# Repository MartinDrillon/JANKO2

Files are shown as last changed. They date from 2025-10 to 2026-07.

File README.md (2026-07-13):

# Clavicore 0.1

Le Clavicore est un contrôleur midi sensible à la vélocité. Il est basé sur la disposition Janko. 
Il fonctionne grâce à des interrupteurs MX magnétiques et un Teensy 4.1.  

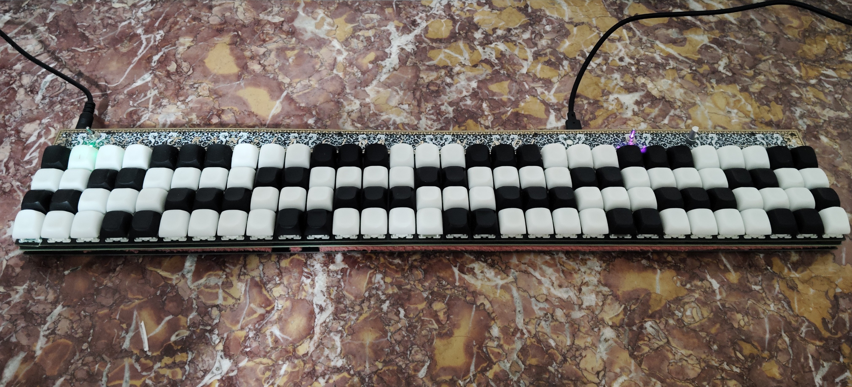
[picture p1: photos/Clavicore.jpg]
Clavicore


---

## JANKO LAYOUT

Contrairement à un piano standard, l’écart physique entre les touches correspond à l’écart musical entre les notes. Il y a un ton de différence sur les lignes et un demi-ton sur les colonnes. Toutes les gammes partagent le même doigté pour des accords identiques et sont jouées de la même manière.  

https://en.wikipedia.org/wiki/Jank%C3%B3_keyboard

## FONCTIONNEMENT

La position des touches est suivie grâce à des capteurs halls. Huit multiplexeurs permettent de transmettre le voltage émis par les 120 capteurs au Teensy. Ses deux ADC échantillonnent chaque touche en 10 bit à 11,4 kHz environ. Plus un touche est enfoncé vite, plus le niveau sonore associé au signal midi est élevé.

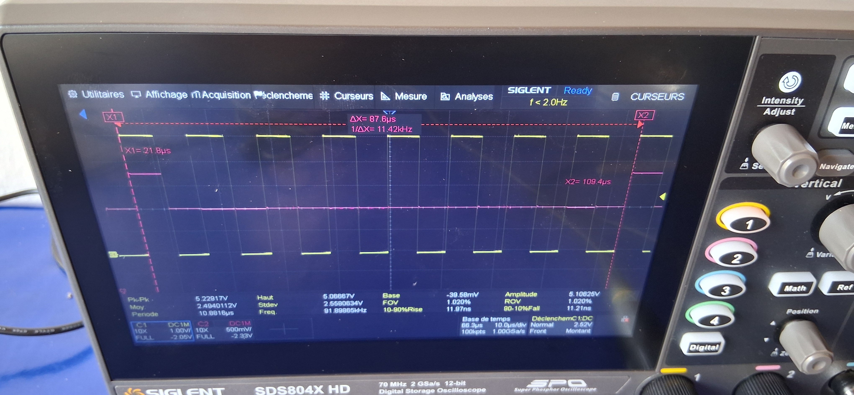
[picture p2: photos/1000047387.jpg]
Une des quatre lignes de sélection du multipleur en jaune, sa sortie en rose, avec une touche pressée : 
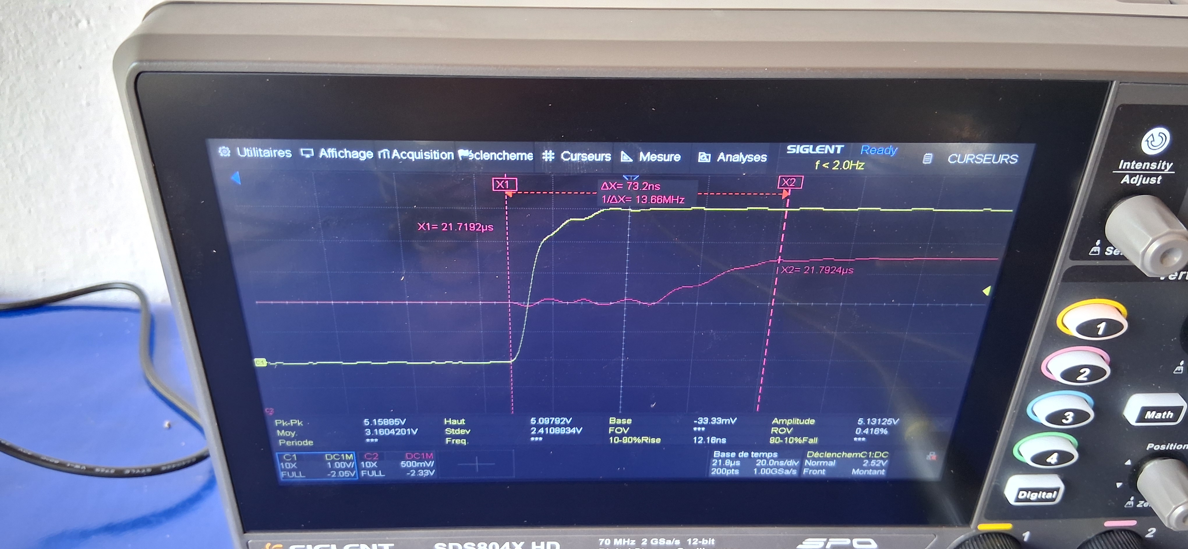
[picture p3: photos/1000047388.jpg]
Stabilisation du signal en sortie du multiplexeur après un changement de channel vers une touche pressée : 

Le schéma du clavicore est disponible ici : 
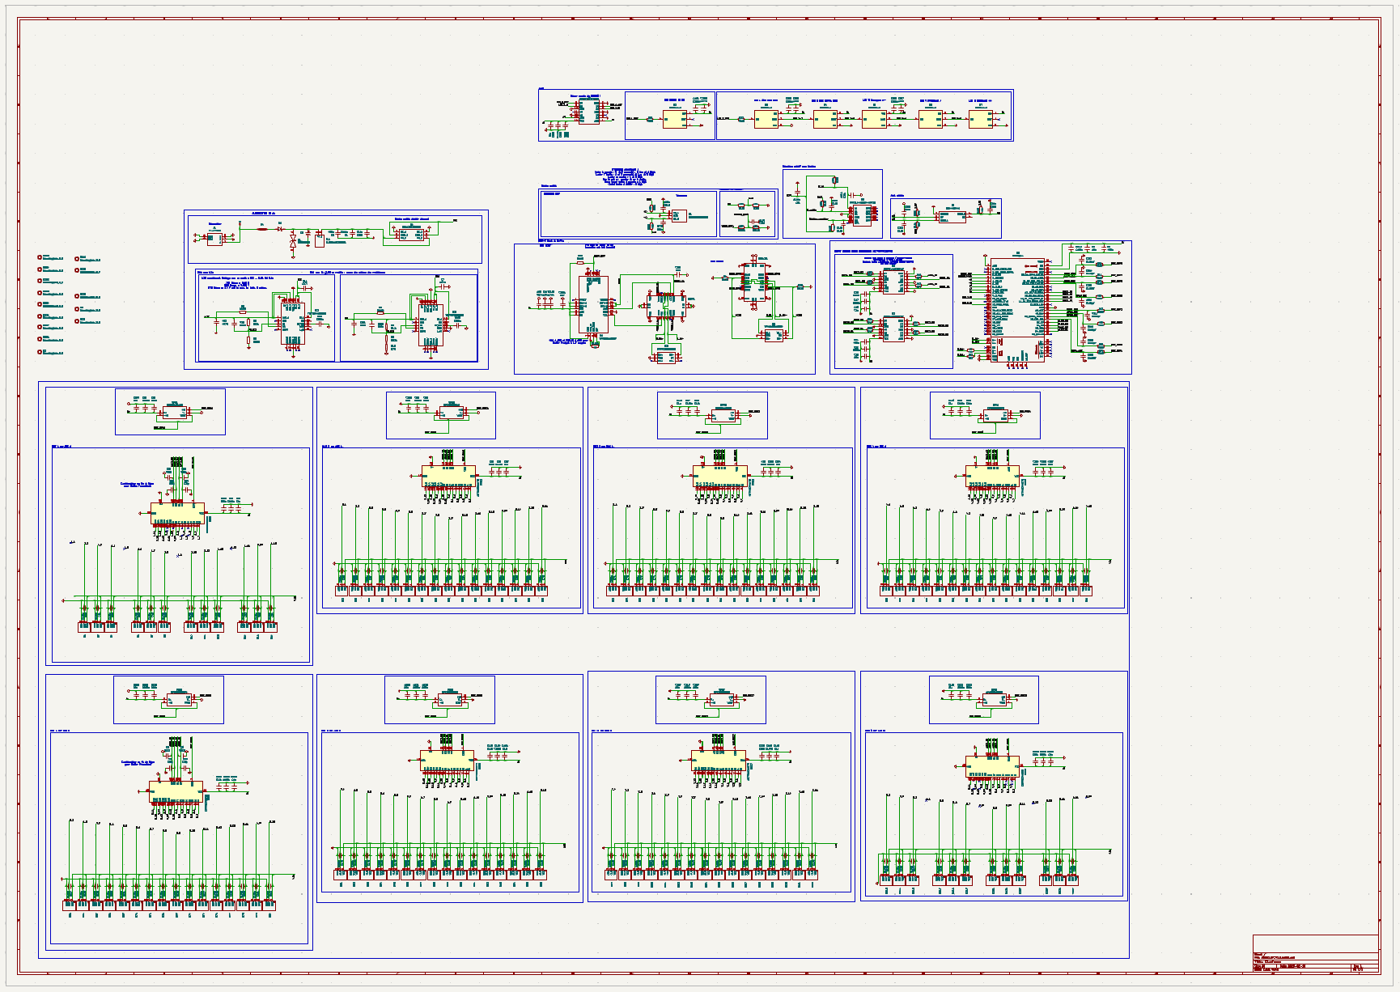
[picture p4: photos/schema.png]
Schéma du clavicore
 

## DÉMONSTRATION

Pour la démonstration de la dynamique de jeu.
https://youtube.com/shorts/Zl-sIEAEMYA?feature=share

Après deux semaines de pratique. Je ne suis pas musicien. Je sais qu’il n’y avait pas besoin de faire un clavier dynamique si c’est pour jouer du clavecin.
https://www.youtube.com/shorts/t3_tYI92ahw

Pour l’esthétique. C’est du plaqué or. J’ai vectorisé le texte du couvercle d’un clavecin ancien et diverses autres images.  
https://youtube.com/shorts/kKriU0rGM7M?feature=share

## LA SUITE

* Faire un vrais boitier
* Recommencer avec une disposition Wiki-Haydn et un STM32 ! 
* Intégrer quelques modules de synthé directement dans le Teensy, si possible ? Voir un séquenceur, etc. 

---

### CREDIT

Pour la preuve qu’il est possible de calculer efficacement une dynamique de jeu avec des capteurs halls :  
https://github.com/aleathwick/midi_hammer

Pour la preuve qu’on peut jouer avec des touches MX classiques :  
https://github.com/KOOPInstruments/melodicade_mx

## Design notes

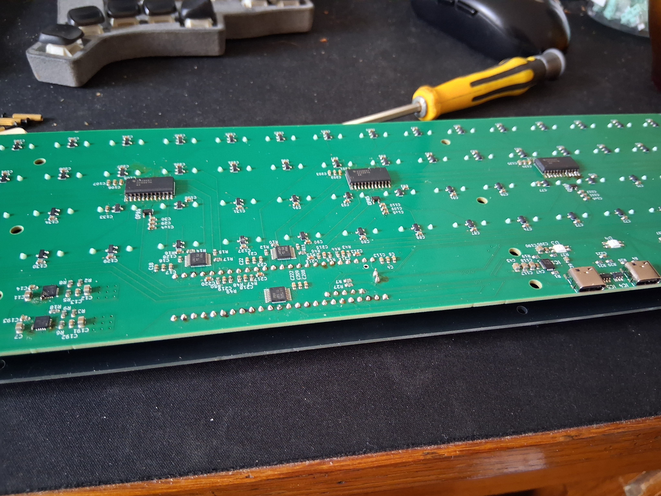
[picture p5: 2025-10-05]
photos/Clavicore_0_1_PCB.jpg

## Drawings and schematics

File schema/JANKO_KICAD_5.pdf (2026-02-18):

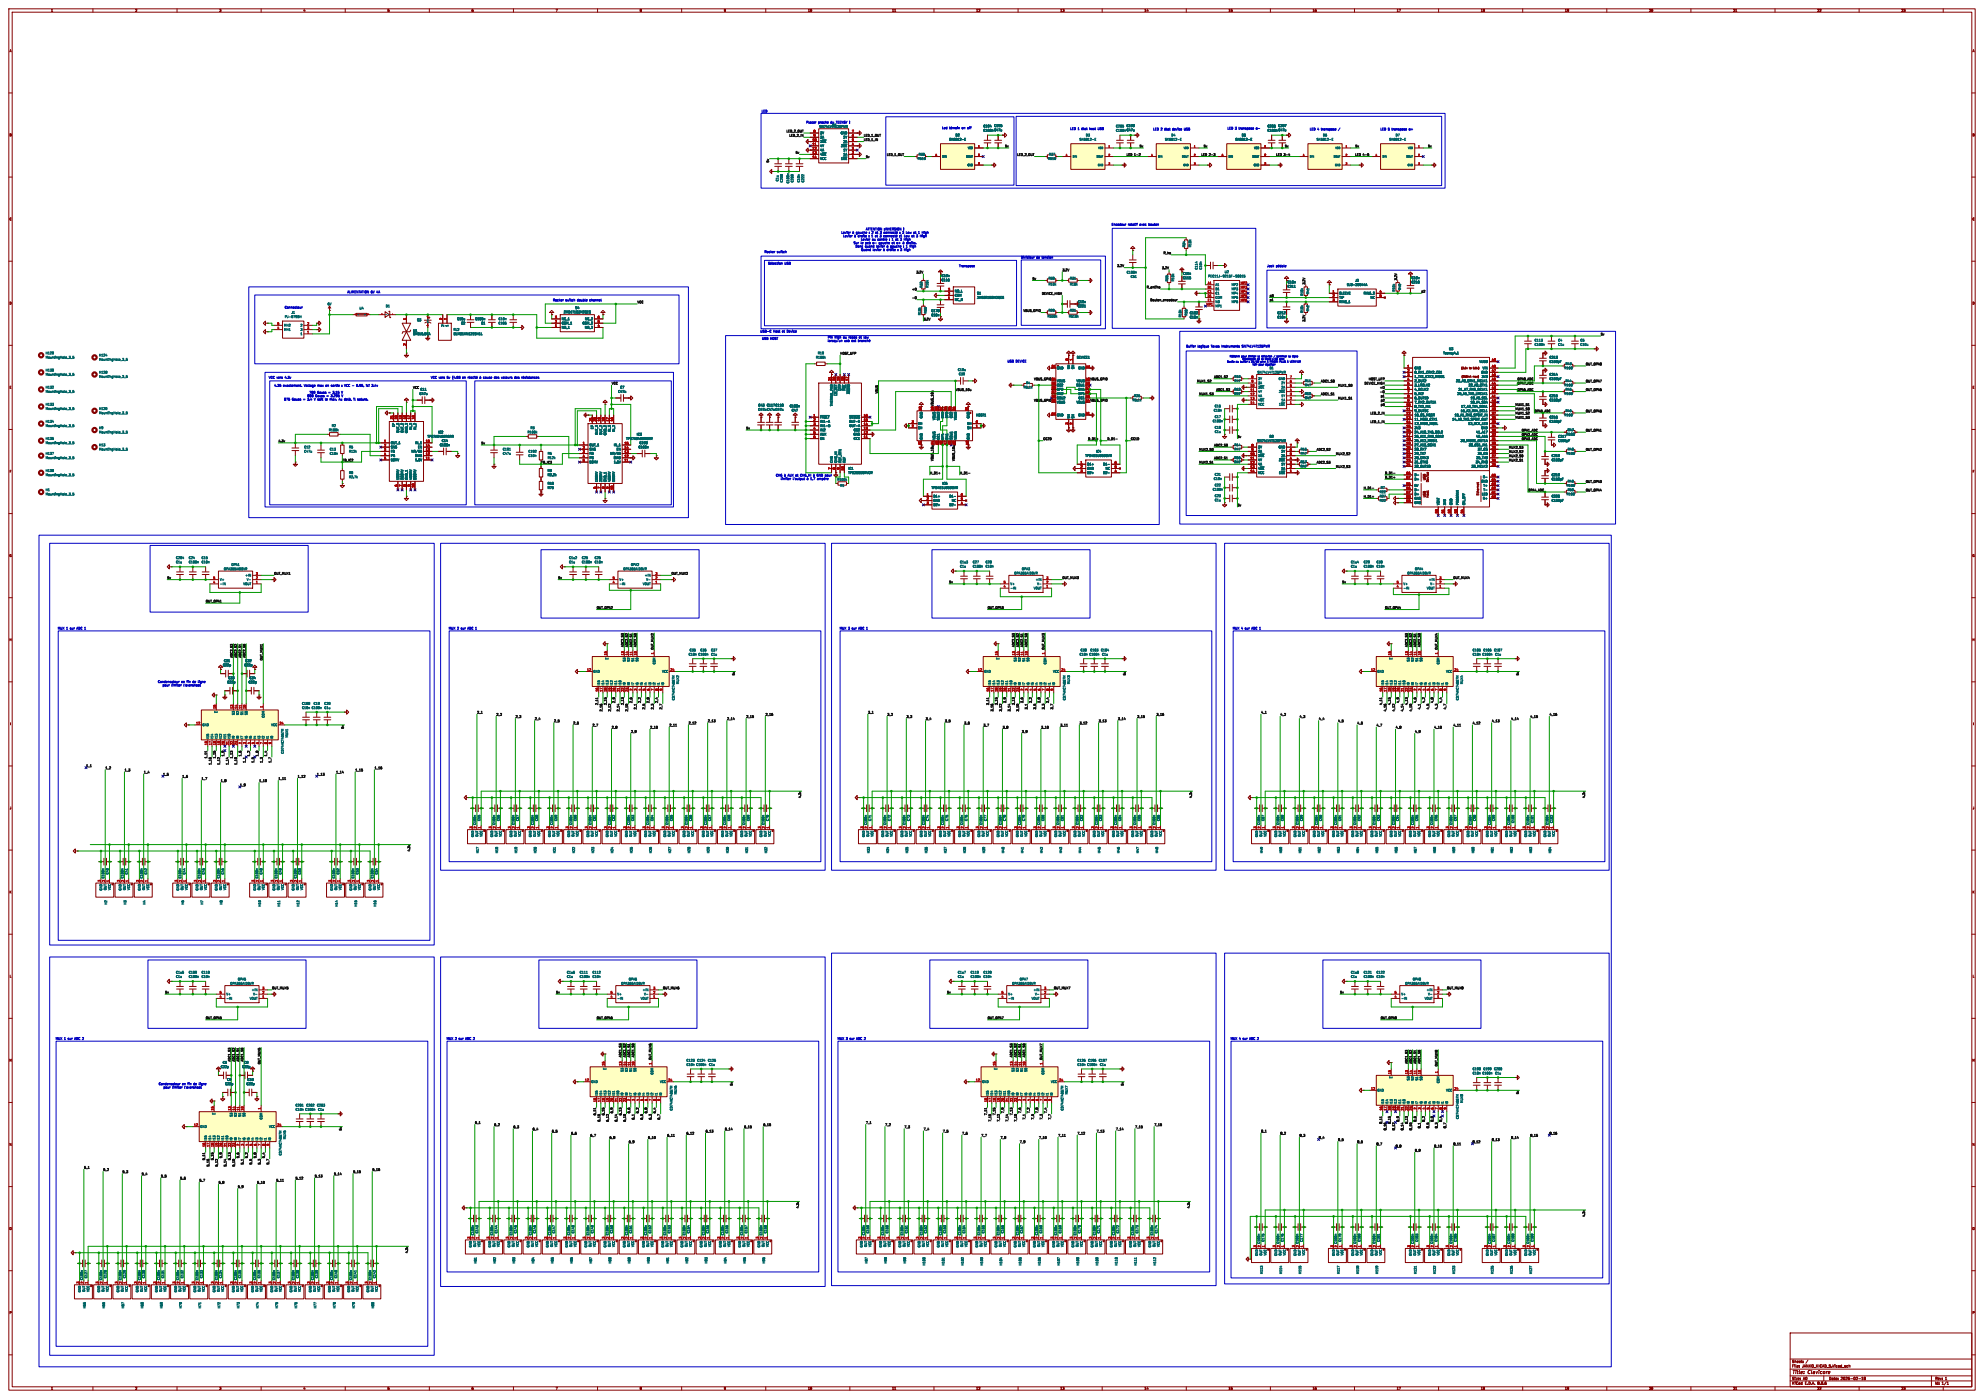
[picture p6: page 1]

Led þÿtémoin on off ALIMENTATION 6V 4A

LED 1 þÿétat host USB

ATTENTION þÿ: /INVERSION ! Levier þÿàgauche : 2 et 3 þÿconnecté : 3 Low et 1 High
3.2V VBUS

Levier þÿàdroite : 1 et 3 þÿconnecté þÿ: /1 Low et 3 High
Levier au centre : 1 et 3 High Sur le pcb o- gauche et o+ þÿàdroite. Donc quand levier þÿàgauche : 1 high Quand levier þÿàdroite : þÿ /3high

þÿSélection USB USB-C Host et Device

Transpose CHG þÿàAUX et CHG_HI þÿàGND pour

Pin high au repos et low

þÿImpédance de la trace : 50 ohm

15 ~{DEBUG}16 ~{AUDIO}17 ~{POL}18 ~{UFP}19

3 H69 OUT_1 1 800MV 10 1.6V 11 BIAS 12 NR/SS 13 EN 14

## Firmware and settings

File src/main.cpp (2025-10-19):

// JANKO2 - 8x16 MUX Controller with dual-ADC parallel scanning
// True parallel scanning: ADC0 + ADC1 simultaneous reads

#include <Arduino.h>
#include <ADC.h>
#include "config.h"
#include "simple_leds.h"
#include "velocity_engine.h"
#include "velocity_calc.h"
#include "calibration.h"
#include "note_map.h"
#include "io_state.h"
#include "key_state.h"
#include "calibration.h"
#include "midi_out.h"
#include <imxrt.h>  // pour DWT cycle counter (Teensy 4.x)
#if DEBUG_ADC_MONITOR
#include "adc_monitor.h"
#endif

// === Runtime velocity gamma (adjustable via encoder) ===
float gVelocityGamma = kVelocityGammaDefault;

// === ADC Instance ===
static ADC gAdc;

// === Fast MUX Channel Switching LUT ===
// Pre-calculated GPIO states for each channel (0-15)
struct ChannelGPIO {
    uint8_t groupA_S0, groupA_S1, groupA_S2, groupA_S3;
    uint8_t groupB_S0, groupB_S1, groupB_S2, groupB_S3;
};

// LUT for fast channel switching (avoids bit operations in loop)
static constexpr ChannelGPIO CHANNEL_LUT[16] = {
    // Ch0: 0000
    {LOW, LOW, LOW, LOW, LOW, LOW, LOW, LOW},
    // Ch1: 0001  
    {HIGH, LOW, LOW, LOW, HIGH, LOW, LOW, LOW},
    // Ch2: 0010
    {LOW, HIGH, LOW, LOW, LOW, HIGH, LOW, LOW},
    // Ch3: 0011
    {HIGH, HIGH, LOW, LOW, HIGH, HIGH, LOW, LOW},
    // Ch4: 0100
    {LOW, LOW, HIGH, LOW, LOW, LOW, HIGH, LOW},
    // Ch5: 0101
    {HIGH, LOW, HIGH, LOW, HIGH, LOW, HIGH, LOW},
    // Ch6: 0110
    {LOW, HIGH, HIGH, LOW, LOW, HIGH, HIGH, LOW},
    // Ch7: 0111
    {HIGH, HIGH, HIGH, LOW, HIGH, HIGH, HIGH, LOW},
    // Ch8: 1000
    {LOW, LOW, LOW, HIGH, LOW, LOW, LOW, HIGH},
    // Ch9: 1001
    {HIGH, LOW, LOW, HIGH, HIGH, LOW, LOW, HIGH},
    // Ch10: 1010
    {LOW, HIGH, LOW, HIGH, LOW, HIGH, LOW, HIGH},
    // Ch11: 1011
    {HIGH, HIGH, LOW, HIGH, HIGH, HIGH, LOW, HIGH},
    // Ch12: 1100
    {LOW, LOW, HIGH, HIGH, LOW, LOW, HIGH, HIGH},
    // Ch13: 1101
    {HIGH, LOW, HIGH, HIGH, HIGH, LOW, HIGH, HIGH},
    // Ch14: 1110
    {LOW, HIGH, HIGH, HIGH, LOW, HIGH, HIGH, HIGH},
    // Ch15: 1111
    {HIGH, HIGH, HIGH, HIGH, HIGH, HIGH, HIGH, HIGH}
};

// === USB MIDI is built-in on Teensy ===
// No additional setup required

// === Calibration Removed ===
// Dynamic calibration logic has been fully removed in the simplified velocity design.
// Thresholds are now fixed constants defined in calibration.h. All related state,
// histograms, and timing have been stripped to reduce latency.

// --- Scanning State ---
uint8_t currentChannel = 0;
uint32_t lastScanUs = 0;
// Frame rate instrumentation
#if DEBUG_FRAME_RATE
static uint32_t gFrameCount = 0;
static uint32_t gLastFrameReportMs = 0;
#endif
// Profiling instrumentation
#if DEBUG_PROFILE_SCAN
static uint64_t gAccumChannelTimeUs = 0;   // somme durées individuelles channels
static uint32_t gChannelSamples = 0;       // nombre de channels mesurés
static uint32_t gFrameAccumTimeUs = 0;     // somme durées frames
static uint32_t gFrameSamples = 0;         // nombre de frames mesurées
static uint32_t gFrameStartUs = 0;         // début frame courante
static uint32_t gChannelMaxUs = 0;         // max channel observé sur intervalle
#endif
// Duplicate detection instrumentation
#if DEBUG_DUPLICATE_DETECT
static uint32_t gDuplicatePairs = 0;          // total paires détectées identiques
static uint32_t gDuplicateFrames = 0;         // frames contenant au moins 1 duplication
static uint32_t gFramesSinceDupPrint = 0;     // compteur de frames pour périodicité
#endif



// --- Function Declarations ---
// (Calibration functions removed)

// --- Dual MUX Control Functions ---
// --- Ultra-Fast MUX Channel Setting with LUT ---
void setMuxChannel(uint8_t channel) {
    const ChannelGPIO& gpio = CHANNEL_LUT[channel];
    
    // Set Group A (S0-S3) with pre-calculated values
    digitalWriteFast(kMuxGroupA_S0, gpio.groupA_S0);
    digitalWriteFast(kMuxGroupA_S1, gpio.groupA_S1);
    digitalWriteFast(kMuxGroupA_S2, gpio.groupA_S2);
    digitalWriteFast(kMuxGroupA_S3, gpio.groupA_S3);
    
    // Set Group B (S0-S3) with pre-calculated values
    digitalWriteFast(kMuxGroupB_S0, gpio.groupB_S0);
    digitalWriteFast(kMuxGroupB_S1, gpio.groupB_S1);
    digitalWriteFast(kMuxGroupB_S2, gpio.groupB_S2);
    digitalWriteFast(kMuxGroupB_S3, gpio.groupB_S3);
}

void initializeDualMux() {
    // Initialize Group A control pins
    pinMode(kMuxGroupA_S0, OUTPUT);
    pinMode(kMuxGroupA_S1, OUTPUT);
    pinMode(kMuxGroupA_S2, OUTPUT);
    pinMode(kMuxGroupA_S3, OUTPUT);
    
    // Initialize Group B control pins
    pinMode(kMuxGroupB_S0, OUTPUT);
    pinMode(kMuxGroupB_S1, OUTPUT);
    pinMode(kMuxGroupB_S2, OUTPUT);
    pinMode(kMuxGroupB_S3, OUTPUT);
    
    // Standard ADC configuration for now (we'll optimize with ADC lib later)
    analogReadResolution(kAdcResolution);
    
    // === ADC Library Configuration ===
    // Calibrate both ADCs
    gAdc.adc0->calibrate();
    gAdc.adc1->calibrate();
    
    // Set to no averaging for maximum speed
    gAdc.adc0->setAveraging(1);
    gAdc.adc1->setAveraging(1);
    
    // Set maximum conversion speed
    gAdc.adc0->setConversionSpeed(ADC_CONVERSION_SPEED::VERY_HIGH_SPEED);
    gAdc.adc1->setConversionSpeed(ADC_CONVERSION_SPEED::VERY_HIGH_SPEED);
    
    // Set maximum sampling speed
    gAdc.adc0->setSamplingSpeed(ADC_SAMPLING_SPEED::VERY_HIGH_SPEED);
    gAdc.adc1->setSamplingSpeed(ADC_SAMPLING_SPEED::VERY_HIGH_SPEED);
    
    // Serial prints removed for performance
}

// --- Cycle counter init (DWT) ---
static inline void enableCycleCounter() {
    // Teensy 4.x (IMXRT) expose ARM DWT registers via imxrt.h macros
    // ARM_DEMCR_TRCENA enables trace (needed for DWT cycle counter)
    ARM_DEMCR |= ARM_DEMCR_TRCENA;    // enable trace
    ARM_DWT_CYCCNT = 0;               // reset cycle counter
    ARM_DWT_CTRL |= 1;                // enable CYCCNT (bit 0)
}
static inline uint32_t readCycleCounter() { return ARM_DWT_CYCCNT; }

// --- Optimized Scanning with LUT and Synchronized ADC ---
void scanChannelDualADC(uint8_t channel) {
    // Optional debug channel freeze
    #if (DEBUG_FREEZE_CHANNEL >= 0)
    channel = DEBUG_FREEZE_CHANNEL % N_CH;
    #endif

    // Set MUX channel with ultra-fast LUT (both groups simultaneously)
    setMuxChannel(channel);

    // Allow MUX outputs + sample/hold buffers to settle
    delayMicroseconds(kSettleMicros);

    // Timestamp as close as possible to first acquisition (pre-loop)
    uint32_t timestamp_us = micros();

        // Perform four synchronized dual-ADC reads (must do all 4 to avoid cloned values)
        // EXACT SPECIFIED IMPLEMENTATION with selectable order and per-pair debug
        uint16_t values[8];
    for (int i = 0; i < 4; ++i) {
            #if ADC_SYNC_ORDER == 0
                // Ordre (ADC0, ADC1) — souvent attendu par pedvide sur T4.1
                const int pin_adc0 = MUX_ADC_PINS[4 + i];  // 20,21,22,23
                const int pin_adc1 = MUX_ADC_PINS[i];      // 41,40,39,38
                gAdc.startSynchronizedSingleRead(pin_adc0, pin_adc1);
                ADC::Sync_result r = gAdc.readSynchronizedSingle();
                values[i]     = r.result_adc1;  // MUX i     → ADC1 → pins 41,40,39,38
                values[4 + i] = r.result_adc0;  // MUX 4+i   → ADC0 → pins 20,21,22,23
            #else
                // Ordre (ADC1, ADC0)
                const int pin_adc1 = MUX_ADC_PINS[i];      // 41,40,39,38
                const int pin_adc0 = MUX_ADC_PINS[4 + i];  // 20,21,22,23
                gAdc.startSynchronizedSingleRead(pin_adc1, pin_adc0);
                ADC::Sync_result r = gAdc.readSynchronizedSingle();
                values[i]     = r.result_adc1;  // MUX i     → ADC1
                values[4 + i] = r.result_adc0;  // MUX 4+i   → ADC0
            #endif

            #if DEBUG_PRINT_PAIRS
                // Pair debug removed
            #endif
            // Pause optionnelle entre paires pour éviter des lectures clonées.
            if (kPerPairDelayMicros > 0) {
                delayMicroseconds(kPerPairDelayMicros);
            } else if (kPerPairDelayCycles > 0) {
                // Attente fine en cycles CPU
                uint32_t start = readCycleCounter();
                while ((readCycleCounter() - start) < kPerPairDelayCycles) { __asm__ volatile("nop"); }
            }
        }

    // Process all 8 keys (always active; no calibration phase)
    for (uint8_t mux = 0; mux < 8; mux++) {
        VelocityEngine::processKey(mux, channel, values[mux], timestamp_us);
#if DEBUG_ADC_MONITOR
        // Met à jour le moniteur si c'est la combinaison surveillée
        AdcMonitor::updateIfMatch(mux, channel, values[mux], timestamp_us);
#endif
    }

#if DEBUG_DUPLICATE_DETECT
    // Détection duplication: compare valeurs[0..3] vs valeurs[4..7]
    bool frameDup = false; // dans ce channel
    for (int i=0;i<4;i++) {
        int16_t d = (int16_t)values[i] - (int16_t)values[4+i];
        if (d < 0) d = -d;
        if (d <= (int16_t)kDuplicateTolerance) {
            gDuplicatePairs++;
            frameDup = true;
        }
    }
    if (frameDup) gDuplicateFrames++;
#endif

    // Optional debug print
    // Value debug removed
}


void setup() {
    // Serial interface removed
    
    // Initialize dual MUX hardware
    initializeDualMux();
    setMuxChannel(currentChannel);
    lastScanUs = micros();
#if DEBUG_PROFILE_SCAN
    gFrameStartUs = lastScanUs;
#endif
    
    // Initialize LEDs
    simpleLedsInit();
    // Initialize I/O state (rocker pins)
    IoState::init();
    
    // Calibration LEDs no longer used (ensure off)
    setCalibrationLeds(false);

#if DEBUG_ADC_MONITOR
    AdcMonitor::begin();
#endif

#if DEBUG_FRAME_RATE && DEBUG_FRAME_RATE_TOGGLE_LED
    pinMode(13, OUTPUT); // LED intégrée Teensy
    digitalWriteFast(13, LOW);
#endif
    
    // Initialize velocity engine
    VelocityEngine::initialize();
    // Initialize MIDI output queue
    MidiOut::init();
    // Init static thresholds (Phase1 dynamique) and load velocity gamma from EEPROM
    calibrationInitStatic();
    // Load velocity gamma from EEPROM if available
    {
        uint16_t tmpLow[N_MUX][N_CH], tmpHigh[N_MUX][N_CH];
        float tmpGamma = kVelocityGammaDefault;
        if (EepromStore::load(tmpLow, tmpHigh, &tmpGamma)) {
            gVelocityGamma = tmpGamma;
        }
    }
    // Set LED brightness to constant value (no longer adjustable via encoder)
    simpleLedsSetBrightness(kLedBrightness);
    // Ne pas démarrer de calibration au boot: conserver les seuils EEPROM
    enableCycleCounter();
    
    // Ready banner removed
    
        // === ADC Pin Mapping Sanity Check (dynamic) ===
        // Pin mapping sanity print removed
    
    // Show current note mapping
    // printNoteMap removed (Serial use)
}

void loop() {
    const uint32_t nowUs = micros();
    // (Calibration state management removed)

    // === Main scanning loop ===
    // Prépare éventuel changement LED (sans show())
    simpleLedsUpdateInputState();
    if (kContinuousScan) {
        // Pas d'attente: enchaîne directement
        uint32_t t0 = micros();
        scanChannelDualADC(currentChannel);
        uint32_t t1 = micros();
#if DEBUG_PROFILE_SCAN
        uint32_t chDur = t1 - t0;
        gAccumChannelTimeUs += chDur;
        gChannelSamples++;
        if (chDur > gChannelMaxUs) gChannelMaxUs = chDur;
#endif
        currentChannel = (currentChannel + 1) % N_CH;
        if (currentChannel == 0) {
            g_acquisition.swapBuffers();
            // Phase2 ingestion frame pour médiane Low
            if (calibrationIsCollecting()) {
                calibrationFrameIngest(g_acquisition.workingValues); // workingValues encore valides juste après swap
            }
#if DEBUG_PROFILE_SCAN
            uint32_t nowUsFrame = micros();
            uint32_t frameDur = nowUsFrame - gFrameStartUs;
            gFrameStartUs = nowUsFrame;
            gFrameAccumTimeUs += frameDur;
            gFrameSamples++;
            if (gFrameSamples >= DEBUG_PROFILE_INTERVAL_FRAMES) {
                // Calculs moyens
                uint32_t avgFrameUs = gFrameAccumTimeUs / gFrameSamples;
                uint32_t avgChannelUs = gChannelSamples ? (uint32_t)(gAccumChannelTimeUs / gChannelSamples) : 0;
                Serial.printf("[PROFILE] frames=%lu avgFrame=%luus avgCh=%luus maxCh=%luus fps_est=%lu\n",
                              (unsigned long)gFrameSamples,
                              (unsigned long)avgFrameUs,
                              (unsigned long)avgChannelUs,
                              (unsigned long)gChannelMaxUs,
                              (unsigned long)(avgFrameUs ? (1000000UL / avgFrameUs) : 0));
                // reset interval
                gFrameAccumTimeUs = 0;
                gFrameSamples = 0;
                gAccumChannelTimeUs = 0;
                gChannelSamples = 0;
                gChannelMaxUs = 0;
            }
#endif
#if DEBUG_FRAME_RATE
            gFrameCount++;
#if DEBUG_FRAME_RATE_TOGGLE_LED
            digitalToggleFast(13);
#endif
            uint32_t nowMs = millis();
            if (nowMs - gLastFrameReportMs >= DEBUG_FRAME_RATE_INTERVAL_MS) {
                // Impression minimaliste (peut être filtrée si besoin)
                Serial.printf("FrameRate=%lu fps\n", gFrameCount * 1000UL / (nowMs - gLastFrameReportMs));
                gLastFrameReportMs = nowMs;
                gFrameCount = 0;
            }
#endif
    // Flush LED strip une seule fois par frame (si changement)
    simpleLedsFrameFlush();
    // MIDI: drain queue avec budget court, une seule fois par frame
    MidiOut::service(50);
#if DEBUG_DUPLICATE_DETECT
    gFramesSinceDupPrint++;
    if (gFramesSinceDupPrint >= DEBUG_DUPLICATE_PRINT_INTERVAL_FRAMES) {
    Serial.printf("[DUP] frames=%lu dupFrames=%lu dupPairs=%lu ratioFrames=%.4f ratioPairs=%.4f\n",
        (unsigned long)gFramesSinceDupPrint,
        (unsigned long)gDuplicateFrames,
        (unsigned long)gDuplicatePairs,
        gFramesSinceDupPrint ? (double)gDuplicateFrames / (double)gFramesSinceDupPrint : 0.0,
    gFramesSinceDupPrint ? (double)gDuplicatePairs / (double)(gFramesSinceDupPrint*4) : 0.0);
        gFramesSinceDupPrint = 0;
        gDuplicateFrames = 0;
        gDuplicatePairs = 0;
    }
#endif
        }
    } else if (nowUs - lastScanUs >= kScanIntervalMicros) {
        lastScanUs = nowUs;
        uint32_t t0 = micros();
        scanChannelDualADC(currentChannel);
        uint32_t t1 = micros();
#if DEBUG_PROFILE_SCAN
        uint32_t chDur = t1 - t0;
        gAccumChannelTimeUs += chDur;
        gChannelSamples++;
        if (chDur > gChannelMaxUs) gChannelMaxUs = chDur;
#endif
        currentChannel = (currentChannel + 1) % N_CH;
        if (currentChannel == 0) {
            g_acquisition.swapBuffers();
            if (calibrationIsCollecting()) {
                calibrationFrameIngest(g_acquisition.workingValues);
            }
#if DEBUG_PROFILE_SCAN
            uint32_t nowUsFrame = micros();
            uint32_t frameDur = nowUsFrame - gFrameStartUs;
            gFrameStartUs = nowUsFrame;
            gFrameAccumTimeUs += frameDur;
            gFrameSamples++;
            if (gFrameSamples >= DEBUG_PROFILE_INTERVAL_FRAMES) {
                uint32_t avgFrameUs = gFrameAccumTimeUs / gFrameSamples;
                uint32_t avgChannelUs = gChannelSamples ? (uint32_t)(gAccumChannelTimeUs / gChannelSamples) : 0;
                Serial.printf("[PROFILE] frames=%lu avgFrame=%luus avgCh=%luus maxCh=%luus fps_est=%lu\n",
                              (unsigned long)gFrameSamples,
                              (unsigned long)avgFrameUs,
                              (unsigned long)avgChannelUs,
                              (unsigned long)gChannelMaxUs,
                              (unsigned long)(avgFrameUs ? (1000000UL / avgFrameUs) : 0));
                gFrameAccumTimeUs = 0;
                gFrameSamples = 0;
                gAccumChannelTimeUs = 0;
                gChannelSamples = 0;
                gChannelMaxUs = 0;
            }
#endif
#if DEBUG_FRAME_RATE
            gFrameCount++;
#if DEBUG_FRAME_RATE_TOGGLE_LED
            digitalToggleFast(13);
#endif
            uint32_t nowMs = millis();
            if (nowMs - gLastFrameReportMs >= DEBUG_FRAME_RATE_INTERVAL_MS) {
                Serial.printf("FrameRate=%lu fps\n", gFrameCount * 1000UL / (nowMs - gLastFrameReportMs));
                gLastFrameReportMs = nowMs;
                gFrameCount = 0;
            }
#endif
    // Flush LED strip une seule fois par frame (si changement)
    simpleLedsFrameFlush();
    // MIDI: drain queue avec budget court, une seule fois par frame
    MidiOut::service(50);
#if DEBUG_DUPLICATE_DETECT
    gFramesSinceDupPrint++;
    if (gFramesSinceDupPrint >= DEBUG_DUPLICATE_PRINT_INTERVAL_FRAMES) {
    Serial.printf("[DUP] frames=%lu dupFrames=%lu dupPairs=%lu ratioFrames=%.4f ratioPairs=%.4f\n",
        (unsigned long)gFramesSinceDupPrint,
        (unsigned long)gDuplicateFrames,
        (unsigned long)gDuplicatePairs,
        gFramesSinceDupPrint ? (double)gDuplicateFrames / (double)gFramesSinceDupPrint : 0.0,
    gFramesSinceDupPrint ? (double)gDuplicatePairs / (double)(gFramesSinceDupPrint*4) : 0.0);
        gFramesSinceDupPrint = 0;
        gDuplicateFrames = 0;
        gDuplicatePairs = 0;
    }
#endif
        }
    }

    // === Handle other tasks ===
    // USB MIDI is handled automatically
    // (LEDs déjà flush en fin de frame si nécessaire)

    // Centralized I/O service (non-blocking, slow polling)
    static IoState::RockerStatus rs; // cache across loops
    bool changed = IoState::update(millis(), rs);
    if (changed) {
        // Apply transpose and feed LEDs without extra pin reads here
        noteMapSetTranspose(rs.transpose);
        simpleLedsSetRocker(rs.pin4High, rs.pin5High);
        simpleLedsSetButton24(rs.button24Low);
        // Encoder-driven velocity gamma adjustment (±0.02 per detent, inverted)
        if (rs.encDelta != 0) {
            gVelocityGamma -= (float)rs.encDelta * 0.02f;
            // Clamp to reasonable range 0.05..2.0
            if (gVelocityGamma < 0.05f) gVelocityGamma = 0.05f;
            if (gVelocityGamma > 2.0f) gVelocityGamma = 2.0f;
#if DEBUG_GAMMA_MONITOR
            Serial.printf("VelocityGamma=%.3f\n", gVelocityGamma);
#endif
        }
        // Button 24 clicks: short/double saves gamma, triple resets
        if (rs.btn24Click == IoState::Btn24Click::Short || rs.btn24Click == IoState::Btn24Click::Double) {
            // Save current gamma to EEPROM
            EepromStore::save(gThLow, gThHigh, &gVelocityGamma);
#if DEBUG_GAMMA_MONITOR
            Serial.printf("VelocityGamma=%.3f [SAVED to EEPROM]\n", gVelocityGamma);
#endif
        } else if (rs.btn24Click == IoState::Btn24Click::Triple) {
            // Reset gamma to default
            gVelocityGamma = kVelocityGammaDefault;
#if DEBUG_GAMMA_MONITOR
            Serial.printf("VelocityGamma=%.3f [RESET to default]\n", gVelocityGamma);
#endif
        }
    }

#if DEBUG_ADC_MONITOR
    AdcMonitor::printPeriodic();
#endif
    // Service calibration (finalisation médiane)
    calibrationService();
    // Service calibration UX FSM (button 24 control)
    // We call with current millis() and button-24 state exposed by IoState.
    // Use last rocker status cached in rs if available, else poll quickly here.
    calibrationServiceFSM(millis(), rs.button24Low);
}

// (Calibration helper functions removed)


                                                                                                                                                                                                                                                                                                                                                                                                                                                                                                                                                                                                                                                                                                                                                                                                                                                                                                                                                                                                                                                                                                                                                                                                                                                                                                                                                                                                                                                                                                                                                                                                                                                                                                                                                                                                                                                                        

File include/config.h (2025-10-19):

#pragma once
// Configuration for JANKO2 8-MUX dual-ADC controller

#include <Arduino.h>

// === ADC Synchronized Read Order Selector ===
// 0 = startSynchronizedSingleRead(ADC0, ADC1)
// 1 = startSynchronizedSingleRead(ADC1, ADC0)
#ifndef ADC_SYNC_ORDER
#define ADC_SYNC_ORDER 0
#endif

// Temporary debug: print per synchronized pair results
#ifndef DEBUG_PRINT_PAIRS
#define DEBUG_PRINT_PAIRS 1
#endif

// === Hardware Configuration ===
// 8 MUX configuration with 2 ADC groups for true parallel scanning
//
// Wiring Recap (Source of Truth) — Teensy 4.1
// Group A (ADC1, MUX0..MUX3):
//   Select Lines (shared by MUX0..3): S0=35 (LSB), S1=34, S2=36, S3=37 (MSB)
//   COM Outputs → ADC1 inputs:
//     MUX0 COM → 41 (A22 / ADC1)
//     MUX1 COM → 40 (A21 / ADC1)
//     MUX2 COM → 39 (A20 / ADC1)
//     MUX3 COM → 38 (A19 / ADC1)
// Group B (ADC0, MUX4..MUX7):
//   Select Lines (shared by MUX4..7): S0=16 (LSB), S1=17, S2=15, S3=14 (MSB)
//   COM Outputs → ADC0 inputs:
//     MUX4 COM → 20 (A6  / ADC0)
//     MUX5 COM → 21 (A7  / ADC0)
//     MUX6 COM → 22 (A8  / ADC0)
//     MUX7 COM → 23 (A9  / ADC0)
// Channel index (0..15) encoded as (S3 S2 S1 S0) with S0 = LSB for BOTH groups.
// IMPORTANT: Use only MUX_ADC_PINS[] inside scanning (no PAIR* arrays) to avoid logic errors.
static constexpr int N_MUX = 8;        // Total number of multiplexers 
static constexpr int N_CH = 16;        // Channels per multiplexer
static constexpr uint16_t kTotalKeys = N_MUX * N_CH; // 128 keys total

// ADC pins for the 8 MUX outputs - optimized for Teensy 4.1 dual ADC
// Group A (ADC1): MUX 0-3 
// Group B (ADC0): MUX 4-7
static constexpr int MUX_ADC_PINS[N_MUX] = {
    // Group A - ADC1 (pins 38-41)
    41,  // MUX0 → pin 41 (ADC1_0 / A22)
    40,  // MUX1 → pin 40 (ADC1_1 / A21) 
    39,  // MUX2 → pin 39 (ADC1_2 / A20)
    38,  // MUX3 → pin 38 (ADC1_3 / A19)
    // Group B - ADC0 (pins 20-23)
    20,  // MUX4 → pin 20 (ADC0_6 / A6)
    21,  // MUX5 → pin 21 (ADC0_7 / A7)
    22,  // MUX6 → pin 22 (ADC0_8 / A8) 
    23   // MUX7 → pin 23 (ADC0_9 / A9)
};

// Synchronized ADC pairs for parallel reading (Target 2 optimization)
// (Legacy helper arrays kept only for potential diagnostics; NOT to be used in scanChannelDualADC)
static constexpr int PAIR_ADC1_PINS[4] = {41, 40, 39, 38}; // DO NOT USE in scanning logic
static constexpr int PAIR_ADC0_PINS[4] = {20, 21, 22, 23}; // DO NOT USE in scanning logic

// Group configuration for dual ADC scanning
static constexpr int N_GROUPS = 2;
static constexpr int MUX_PER_GROUP = 4;

// CD74HC4067 MUX control pins - separate for each group
// Group A (MUX 0-3) - S0-S3 lines
static constexpr uint8_t kMuxGroupA_S0 = 35; // S0 for group A
static constexpr uint8_t kMuxGroupA_S1 = 34; // S1 for group A  
static constexpr uint8_t kMuxGroupA_S2 = 36; // S2 for group A
static constexpr uint8_t kMuxGroupA_S3 = 37; // S3 for group A

// Group B (MUX 4-7) - S0-S3 lines  
static constexpr uint8_t kMuxGroupB_S0 = 16; // S0 for group B
static constexpr uint8_t kMuxGroupB_S1 = 17; // S1 for group B
static constexpr uint8_t kMuxGroupB_S2 = 15; // S2 for group B
static constexpr uint8_t kMuxGroupB_S3 = 14; // S3 for group B

// Safety check: ensure array size matches N_MUX
static_assert(N_MUX == sizeof(MUX_ADC_PINS)/sizeof(MUX_ADC_PINS[0]), "MUX_ADC_PINS array size must match N_MUX");

// ADC Configuration
static constexpr uint8_t kAdcResolution = 10; // 10-bit ADC (0-1023)

// MIDI Configuration
static constexpr uint8_t kMidiChannel = 1; // MIDI channel (1-16)
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

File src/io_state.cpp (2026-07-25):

#include "io_state.h"

namespace IoState {
    static bool sInited = false;
    static RockerStatus sLast{true, true, 0, false, 0, Btn24Click::None};
    static uint32_t sLastPollMs = 0;
    static constexpr uint32_t kPollPeriodMs = 10; // ~100 Hz
    // Quadrature decoder state
    static volatile int16_t sEncAccum = 0;
    static volatile uint8_t sEncState = 0; // 2-bit: (A<<1)|B
    // Button 24 click detection state
    static bool sBtn24Prev = false; // false = released (HIGH when not pressed)
    static uint32_t sBtn24PressTimeMs = 0;
    static uint8_t sBtn24ClickCount = 0;
    static uint32_t sBtn24LastReleaseMs = 0;
    static constexpr uint32_t kClickWindowMs = 400; // max time between clicks for double/triple
    static constexpr uint32_t kShortPressMaxMs = 300; // short press < 300ms
    static constexpr uint32_t kDebounceMs = 20;

    // Transition table: prev(2b)<<2 | cur(2b) -> delta {-1,0,+1}
    // Valid steps: 00->01(+1), 01->11(+1), 11->10(+1), 10->00(+1)
    // Reverse for -1; all others 0 (including bounces)
    static inline int8_t quadDelta(uint8_t prev, uint8_t cur) {
        uint8_t key = (prev << 2) | cur;
        switch (key) {
            case 0b0001:
            case 0b0111:
            case 0b1110:
            case 0b1000: return +1;
            case 0b0010:
            case 0b1011:
            case 0b1101:
            case 0b0100: return -1;
            default: return 0;
        }
    }

    static void onEncChange() {
        // Read A/B quickly
        uint8_t a = digitalReadFast(kPinEncA) ? 1 : 0;
        uint8_t b = digitalReadFast(kPinEncB) ? 1 : 0;
        uint8_t cur = (a << 1) | b;
        uint8_t prev = sEncState & 0x3;
        if (cur != prev) {
            int8_t d = quadDelta(prev, cur);
            sEncAccum += d;
            sEncState = cur;
        }
    }

    static inline int8_t calcTranspose(bool pin4High, bool pin5High) {
        if (pin4High && pin5High) return 0;   // neutral
        if (pin4High && !pin5High) return -1; // 4 HIGH -> down
        if (!pin4High && pin5High) return +1; // 5 HIGH -> up
        return 0; // both LOW -> neutral
    }

    void init() {
        if (sInited) return;
        pinMode(kPinRocker4, INPUT_PULLUP);
        pinMode(kPinRocker5, INPUT_PULLUP);
        bool p4 = digitalReadFast(kPinRocker4);
        bool p5 = digitalReadFast(kPinRocker5);
        pinMode(kPinButton24, INPUT_PULLUP);
        bool b24low = (digitalReadFast(kPinButton24) == LOW);
    // Encoder inputs as pullups (A/B)
    pinMode(kPinEncA, INPUT_PULLUP);
    pinMode(kPinEncB, INPUT_PULLUP);
    uint8_t a = digitalReadFast(kPinEncA) ? 1 : 0;
    uint8_t b = digitalReadFast(kPinEncB) ? 1 : 0;
    sEncState = (a << 1) | b;
    sEncAccum = 0;
    attachInterrupt(digitalPinToInterrupt(kPinEncA), onEncChange, CHANGE);
    attachInterrupt(digitalPinToInterrupt(kPinEncB), onEncChange, CHANGE);
        // Button 24 click detection init
        sBtn24Prev = b24low;
        sLast.pin4High = p4;
        sLast.pin5High = p5;
        sLast.transpose = calcTranspose(p4, p5);
        sLast.button24Low = b24low;
        sLast.encDelta = 0;
        sLast.btn24Click = Btn24Click::None;
        sLastPollMs = millis();
        sInited = true;
    }

    bool update(uint32_t nowMs, RockerStatus& outStatus) {
        if (!sInited) init();
        if ((nowMs - sLastPollMs) < kPollPeriodMs) {
            outStatus = sLast;
            return false;
        }
        sLastPollMs = nowMs;
        bool p4 = digitalReadFast(kPinRocker4);
        bool p5 = digitalReadFast(kPinRocker5);
        bool b24low = (digitalReadFast(kPinButton24) == LOW);
        int8_t tr = calcTranspose(p4, p5);
    // Drain accumulated quadrature steps since last poll (atomically)
    int16_t acc;
    noInterrupts();
    acc = sEncAccum;
    // Keep remainder so partial transitions aren't lost between polls
    sEncAccum = (int16_t)(acc % 4);
    interrupts();
    // Each valid transition gives +/-1; typical encoders produce 4 transitions per detent.
    // Convert to detents (round toward zero)
    int8_t encDelta = (int8_t)(acc / 4);
        // Button 24 click detection (short/double/triple, not long 3s hold)
        Btn24Click detectedClick = Btn24Click::None;
        if (sBtn24Prev && !b24low) {
            // Button released (pressed->released transition)
            uint32_t pressDur = nowMs - sBtn24PressTimeMs;
            if (pressDur >= kDebounceMs && pressDur < kShortPressMaxMs) {
                // Valid short press (<300ms)
                uint32_t timeSinceLastRelease = nowMs - sBtn24LastReleaseMs;
                if (timeSinceLastRelease < kClickWindowMs && sBtn24ClickCount > 0) {
                    // Within window: increment click count
                    sBtn24ClickCount++;
                } else {
                    // Start new click sequence
                    sBtn24ClickCount = 1;
                }
                sBtn24LastReleaseMs = nowMs;
            }
        } else if (!sBtn24Prev && b24low) {
            // Button pressed (released->pressed transition)
            sBtn24PressTimeMs = nowMs;
        }
        // Check if click window expired
        if (sBtn24ClickCount > 0 && (nowMs - sBtn24LastReleaseMs) >= kClickWindowMs) {
            // Window expired: report accumulated clicks
            if (sBtn24ClickCount == 1) detectedClick = Btn24Click::Short;
            else if (sBtn24ClickCount == 2) detectedClick = Btn24Click::Double;
            else if (sBtn24ClickCount >= 3) detectedClick = Btn24Click::Triple;
#ifdef DEBUG_GAMMA_MONITOR
            Serial.printf("[IoState] Button24 click detected: count=%u type=%d\n", sBtn24ClickCount, (int)detectedClick);
#endif
            sBtn24ClickCount = 0;
        }
        sBtn24Prev = b24low;
        bool changed = (p4 != sLast.pin4High) || (p5 != sLast.pin5High) || (tr != sLast.transpose) || (b24low != sLast.button24Low);
        // Always update btn24Click (even if None) to clear previous clicks
        sLast.pin4High = p4;
        sLast.pin5High = p5;
        sLast.transpose = tr;
        sLast.button24Low = b24low;
        sLast.encDelta = encDelta;
        sLast.btn24Click = detectedClick;
        outStatus = sLast;
        return changed || (encDelta != 0) || (detectedClick != Btn24Click::None);
    }
}

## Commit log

2025-09-14 MUX fonctionnel sauf la rangée du haut
2025-09-14 8MUX2ADC en cours d’optimisation de la fréquence de scan
2025-09-14 Variable de jeu et de scan bcp plus rapide
2025-09-14 seuils manuel création du fichier de base
2025-09-15 retour engine velocité base4 suppresion logique compliqueé
2025-09-15 ajout serial moniteur sur une channel d’un mux
2025-09-16 Nettoyage led et ULTRA BOOST RAPIDIÉ
2025-09-16 nettoyage calibration individuel par touche et légères modifs constantes
2025-09-16 courbe de vélocité linèaire
2025-10-19 retour à une calibration fonctionnelle
2025-10-19 courbe gamma sur l’encodeur
2025-10-19 test calibration sens de touche
2025-10-19 fiabilisation de la calibration en fonction de la polarité
